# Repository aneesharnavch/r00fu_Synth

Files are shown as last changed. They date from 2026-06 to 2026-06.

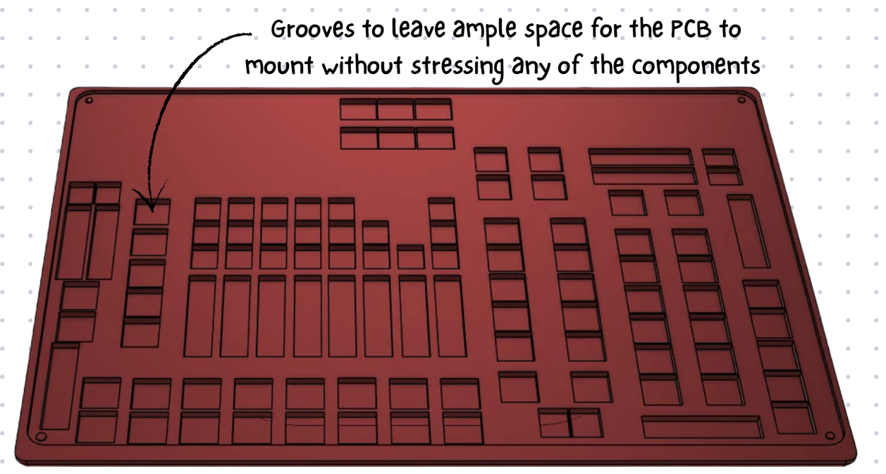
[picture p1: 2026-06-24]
Assets/Assembly_grooves_pic.png

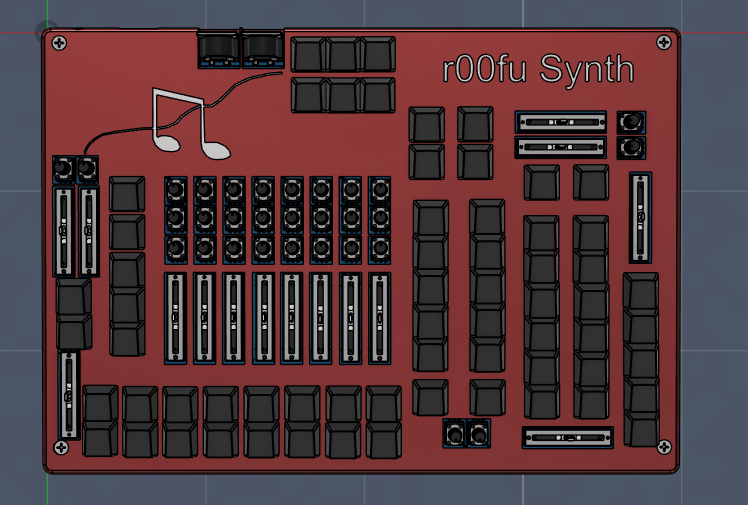
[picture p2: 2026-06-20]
Assets/r00fuSynth_TopDown.png

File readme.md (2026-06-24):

# R00fu Synth
Cover_pic

A digital groove box + synth + MIDI controller crammed into one box. 64 buttons , 25 knobs and 15 sliders to compose any beat you can imagine

# How does it work? 
The primary control is done via an ESP32S3 DevcitC-1 , With its two USB-C ports and it runs on two cores. Core 0 does the digital state checking. It scans all 64 buttons , 25 knobs and 15 sliders once every 1ms reading it through a 74HC4067 Analog MUX chip, It also checks for MIDI in Signal and runs the sequencer. Core 1 only uses the I2S protocol driving audio through the PCM5102A.

It connects to your device by either the USB-C port or DIN MIDI sockets. With everything configured using a modded version of an opensource MIDI configuring python script that runs on a lil python GUI. 

# Why did I make it? 

My friend ( on SoundCloud @r00fu ) is really into music , so being the great friend I am was shocked at how expensive most of the music gear he has is . So me being the dumbass I am proceed to underestimated how complex making a Synthesizer is and try to make one. This is my attempt at going for it. 

# Components Required for the Build

| No. | Quantity | Description | Supplier | Supplier Part | Product Link | Cost | Price (USD) |
|-----|---|---|---|---|---|---|---|
| 1 | 7 | 100nF 0402 Decoupling Capacitor | LCSC | C2888326 | https://www.lcsc.com/product-detail/C2888326.html | 0.00093 | 0.00651 |
| 2 | 6 | 10uF 0402 Decoupling Capacitor | LCSC | C307415 | https://www.lcsc.com/product-detail/C307415.html | 0.1492  | 0.8952 |
| 3 | 4 | 1uF 0603 Charge bank Capacitor | LCSC | C519560 | https://www.lcsc.com/product-detail/C519560.html | 0.0181  | 0.0724 |
| 4 | 1 | 3.5mm Headphone Jack | LCSC | C41347691 | https://www.lcsc.com/product-detail/C41347691.html | 2.273 | 2.273 |
| 5 | 64 | 1N4148W Diode for Switches | LCSC | C917030 | https://www.lcsc.com/product-detail/C917030.html | 0.0061  | 0.3904 |
| 6 | 3 | 220Ω 0603 Resistor | LCSC | C114683 | https://www.lcsc.com/product-detail/C114683.html | 0.00017 | 0.00051 |
| 7 | 1 | 10kΩ 0603 Resistor | LCSC | C95204 | https://www.lcsc.com/product-detail/C95204.html | 0.0241  | 0.0241 |
| 8 | 30 | 10kΩ Knob Potentiometer | LCSC | C209779 | https://www.lcsc.com/product-detail/C209779.html | 0.8401  | 25.203 |
| 9 | 15 | 10kΩ Slide Potentiometer | LCSC | C5357832 | https://www.lcsc.com/product-detail/C5357832.html | 2.82 | 42.3 |
| 10  | 2 | DIN connector for MiDi | LCSC | C2939347 | https://www.lcsc.com/product-detail/C2939347.html | 0.3249  | 0.6498 |
| 11  | 1 | Optocoupler for MiDi In setup | LCSC | C20082 | https://www.lcsc.com/product-detail/C20082.html | 0.5521  | 0.5521 |
| 12  | 1 | Amplifier for Headset/Speaker use | LCSC | C1520792 | https://www.lcsc.com/product-detail/C1520792.html | 2.1817  | 2.1817 |
| 13  | 3 | Analog Multiplexer for device management | LCSC | C1545936 | https://www.lcsc.com/product-detail/C1545936.html | 2.71 | 8.13 |
| 14  | 64 | Mechanical Switches | LCSC | C49234238 | https://www.lcsc.com/product-detail/C49234238.html | 0.1068  | 6.8352 |
| 15  | 1 | ESP32-S3-DevKitC-1 Wifi & Blutooth Dev Board | Aliexpress | S3-DevkitC-1-N32R16V | https://www.aliexpress.com/item/1005003979778978.html | 15.52 | 15.52 |
| 16  | 1 | PCB | JLCPCB | NA | https://cart.jlcpcb.com/quote? | 28.4 | 28.4 |
| | | | | | | Total | 133.43392 |
# PCB and Schematic 
I designed it in EasyEDA Pro. You can find the Gerber files in the repo. The schematic and PCB are as follows : - 
SCH_Schematic_r00fu_Synth
PCB_pic

# Assembly 

Please do note that these assembly instructions are not final and can change. I've yet to build it, and when I do, I'll update this section to be more accurate. In the meanwhile, don't be afraid to change things up or make use of the several exposes GPIO pins/testing pad to make any modifications you would like to make. 

Note : Soldering Instructions are SUGGESTIONS and are typically personal preference , If your used to doing things a certain way , do not change it. I personally tend to do SMD components close to THT components first , followed by the THT components . 

1. Since most of the components on this board are THT anyways , I would recommend you start things off by getting all 24 SMD components soldered on. 
2. You can do that by just soldering one end of the SMD capacitor or resistor down with a decent bit of flux to get the part in place 
3. you can follow that up by soldering the other end cleaning the solder joint before checking for continuity on the passives with a multimeter to just verify its alright 
4. Now that you should be done with the SMD parts, you can begin with placing all of the THT components into their place which should be pretty obvious based on physical appearance 
5. I like to be lazy so I usually tape it down from the top to hold onto the parts when i flip the board over to solder the THT elements 
6. Once you've placed all of the parts down (The tape part is optional, feel free to continue without it) , flip the board around and flux the joints up and solder them nice and snug .
7. Make sure the  buttons are snug and level with the bottom before you let the solder reflow and solidify on the joints. The case will be slightly misaligned if you don't solder things in all the way down .
8. Inspect everything with your eyes , looking at every component individually. Its recommended to use an Multimeter or an LCR meter to just sanity check all of the values and check for continuity on all of your passives (you can also sanity check the sliders and knobs if you just plug the board with power)
9. Use some Isopropanol to clean the Flux and solder residue off the board and connect it to a power source to make sure it doesn't explode.

# Case 
The case is a beautiful rectangular enclosure with cutouts for the Knobs, Sliders and Switches with room left for the Keycaps to be put on after assembly. I added a hackclub logo to the back for some represent, pictures showing it are here below : - 

Case_pic
Internal_case_space
r00fuSynth_base

# Setting up the case

The PCB without keycaps on should just drop onto the bottom plate of the case and you can align the top plates without much difficulty. Once your done with that , just slot in 4 M4 screws through the screw holes and shown in this picture below and you should be done : - 
r00fuSynth_Assembly_pic
Screw_mount_pic
# Hardware at a Glance 

| Subsystem | What it is |
| --- | --- |
| MCU | ESP32S3-S3-DevkitC1 Dev Board |
| Audio | PCM5102A I2S DAC, 44.1kHz/16-bit stereo audio system |
| Buttons | 8x8 matrix with key diodes , scanned every 1ms |
| Knobs | 25 pots read via 2 MUXes |
| Sliders | 15 Faders read via 3rd MUX |
| MUX | 3 x 74HC4067 (16CH MUX) |
| MIDI | 5 pin DIN in/out boards |
| FX | delay , reverb , chorus , bitcrusher |
# Setting up the Firmware 

The firmware builds on PlatformIO (not the Arduino IDE or the ESP32 IDF) as the code is dependent very much so on several other opensource libraries. 

1. Install PlatformIO if you haven't done so yet , run the following commands in terminal
```cmd
pip install platformio 
pio --version 
```
2. PLUG INTO THE CORRECT USB-C PORT. The DevKitC-1  has two USB-C ports. USE THE USB PORT , NOT THE UART ONE. 
3.  Flashing the firmware for the first time needs you to enter board in boot mode so just 
	**hold `BOOT` → tap `RESET` → release `BOOT`**
4. Flash some sort of test sketch to sanity check the board before flashing the firmware using the PlatformIO cli, Just run the following snippet of CMD commands 
```cmd
cd firmware/r00fu_synth
pio run -t uploadfs # settings and partition 
pio run -t upload # the actual firmware
```
once you get the following message on the terminal , You should be done ! 

```cmd
Verifying written data...
Hash of data verified.

Hard resetting via RTS pin...
```
5. Watch it boot:
```cmd
pio device moonitor -b 115200
```
Its done properly if you see : 
```cmd
HELLO r00fu_synth 0.20
LOG r00fu_synth boot complete 
```
pressing any key or move and knob or slider and the serial monitor should spit out the exact id and state of whatever key/knob/slider you've messed with. So you should be done with uploading code onto the board , now time to configure it for your application. 
# Pin map 

This is the wiring the firmware expects. It's all in `include/config.h` , Its the only source of global definitions in the code.

| What | name in code | GPIO pin | Notes |
|---|---|---|---|
| Switch Matrix Rows | ROW_PINS | 4,5,6,7,15,16,17,18 | Low when not in Use |
| Switch Matrix Columns | COL_PINS | 8,9,10,11,12,13,14,21 | Reading with internal pull up |
| MUX select pins | MUX_SEL_PINS | 35,36,37,38 | Shared by all MUX |
| MUX A out | MUX_A_OUT | 1 | MUX A read pin |
| MUX B out | MUX_B_OUT | 2 | MUX B read pin |
| MUX C out | MUX_C_OUT | 3 | MUX C read pin |
| I2S Bit Clock | I2S_BCK_PIN  | 40 | PCM5102A BCK |
| I2S Word Clock | I2S_LRCK_PIN | 41 | PCM5102A LRCK |
| I2S Data | I2S_DOUT_PIN | 42 | PCM5102A DIN |
| MIDI OUT | MIDI_TX_PIN  | 43 | DIN out with current limit |
| MIDI IN | MIDI_RX_PIN  | 44 | DIN in through optocoupler |
# Setting up the the Hardware config ( the software that maps the buttons)

This is the part of the firmware that actually makes the Synth work. run the ``gui/r00fu_config.py`` file to communicate with the synth across USB serial. Pressing a physical button should light up a square on the python GUI and you can configure it  a bunch of different applications. To run it , you only really need python and pyserial installed. If you don't have that done already, just run the following command in your terminal. 

```cmd
pip install pyserial
```

1. run the file now and you should see a dropdown to select the boards COM port 
2. Select the board's COM port and hit connect, the status bar should say some form of connected 
3. once you click a button IRL , you should see it flash in the python script, now on the python script , you can pick one of the functions from the panel : 

| Function  | What it does |
| --- | --- |
| Note | plays a MIDI note (on the synth and out of USB/DIN) |
| CC | command to change MIDI controller (127 on press, 0 on release) |
| Program | sends a program change |
| Transport | Play/ Stop / Record / Continue etc.. |
| Mode | switches the whole box to Drum/StepSeq/Keyboard etc.. |
| None | does nothing |
4. Push to the Device , Sends the whole command map over serial. This data is Saved 
5.  Save/Load dumps the map to a config .json file 
# First boot and Setup 
- Plug into the USB port and plug in Headphones or an Amp into the PCM5102A's Headphone jack
- It should boot straight into Drum mode (LED should go yellow). assuming you've set the config with drum notes on the hardware config. 
- Turn a knob , the synth should reach. If knobs feel jittery/laggy then please increase the `ANALOG_SMOOTHING` parameter in the code
- Have a blast , it appears to be working as intended 

If you do run into issues ? Most of the time its :- 
- Wrong USB port
- button not mapped to note yet 
- SCK not tied to ground properly
# Some examples of actually using it 

This is the fun part. The box is **5 instruments**, and you flip between them with a button you mapped to **Mode** (or send it from the GUI). The LED colour tells you where you are.

### Mode 0 Drum Machine :
8 drum tracks, the grid is your pads. Each pad is mapped (in the GUI) to a note that triggers a drum voice. Tap pads to play in real time.

### Mode 1 Step Sequencer :

The 64 buttons are physically wired to resemble a keyboard with 64 Switches, Some of the things you can use the boat for are :

- mute/unmute tracks
- parameter locks
- swing 
- pattern chaining

### Mode 2 Keyboard : 

The grid becomes notes. Set you need to setup a  scale In the python script so every key you hit is in-key. Use **chord mode** to slam triads with the buttons and move notes around with the slider

### Mode 3  DAW Controller :

It's a USB-MIDI control surface. So you can just plug the USB port into your computer, open your DAW, and configure the following items :- 
- buttons (Can be mapped to litterally anything a macro can be mapped to )
- 25 knobs (map them to plugin params, sends, whatever)
- 15 sliders  (for faders or volume for individual subtracks)  
    Everything leaves over USB-MIDI for the host to learn. This is the "I want the full DAW but I hate the mouse" mode.

# Code Tweaks / Example implementation

You can tune the switch matrix input stuff by changing
include/config.h:
```cpp
static const int ROW_PINS[MATRIX_ROWS] = { 8, 9, 10, 11, 12, 13, 14, 21 }; // COLS
static const int COL_PINS[MATRIX_COLS] = { 4, 5, 6, 7, 15, 16, 17, 18 };   //ROWS
```

If your Knobs too jittery / too sluggish: change the smoothing. General Rule of Thumb Higher = smoother but laggier.
include/config.h:
```cpp
#define ANALOG_SMOOTHING 0.10f   
```

Buttons feel weird / mis-inputs: tune the debounce (how many stable 1 ms samples before it commits).
include/config.h:
```cpp
#define MATRIX_DEBOUNCE_COUNT 6  // lower = snappier but bouncier and vice versa
```

If you want more voices or want to prioritize vocals change : 
include/config.h:
```cpp
#define NUM_VOICES 8  
```

# Files 
```cmd
C:.
│   BOM_r00fu_synth.csv
│   readme.md
│   Zine_r00fu_Synth.pdf
│
├───Assets
│       PCB_3D_Render_No_assembly_pic.png
│       PCB_pic .png
│       r00fuSynth_Assembly.png
│       r00fuSynth_Assembly_pic.png
│       r00fuSynth_base.png
│       r00fuSynth_TopDown.png
│       SCH_Schematic_r00fu_Synth.png
│       Zine_r00fu_Synth.png
│
├───CAD_Files
│       r00fusynth.f3z
│       r00fusynth.step
│
├───Firmware
│   ├───gui
│   │   │   r00fu_config.py
│   │   │   README.md
│   │   │
│   │   └───__pycache__
│   │           r00fu_config.cpython-314.pyc
│   │
│   ├───prototype_single_file
│   │       r00fu_synth_prototype.ino
│   │
│   └───r00fu_synth
│       │   platformio.ini
│       │   SETUP.md
│       │
│       ├───data
│       ├───include
│       │       config.h
│       │       events.h
│       │       midi_map.h
│       │
│       └───src
│           │   main.cpp
│           │
│           ├───audio
│           │       adsr.cpp
│           │       adsr.h
│           │       effects.cpp
│           │       effects.h
│           │       filter.cpp
│           │       filter.h
│           │       oscillator.cpp
│           │       oscillator.h
│           │       synth.cpp
│           │       synth.h
│           │       voice.cpp
│           │       voice.h
│           │
│           ├───drivers
│           │       button_matrix.cpp
│           │       button_matrix.h
│           │       config_protocol.cpp
│           │       config_protocol.h
│           │       midi_din.cpp
│           │       midi_din.h
│           │       mux.cpp
│           │       mux.h
│           │       pcm5102.cpp
│           │       pcm5102.h
│           │       usb_midi.cpp
│           │       usb_midi.h
│           │
│           ├───sequencer
│           │       sequencer.cpp
│           │       sequencer.h
│           │
│           ├───storage
│           │       midi_map.cpp
│           │       presets.cpp
│           │       presets.h
│           │       settings.cpp
│           │       settings.h
│           │
│           ├───system
│           │       events.cpp
│           │       tasks.cpp
│           │       tasks.h
│           │
│           └───ui
│                   modes.cpp
│                   modes.h
│
└───PCB_Files
        Gerber_r00fu_Synth.zip
        PickAndPlace_r00fu_Synth .xlsx
        Source_r00fu_Synth .epro
```
# Zine 
Zine_r00fu_Synth

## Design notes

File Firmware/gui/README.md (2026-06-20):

# r00fu_synth — Button Configurator

A desktop tool to **detect** every physical button on the groovebox and
**map** each one to a function (MIDI note / CC / Program / Transport / Mode).
Built for a music producer: the same map drives the standalone groovebox *and*
turns it into a USB-MIDI control surface in Ableton / FL / Reaper / Bitwig.

## Setup
```
pip install pyserial
python r00fu_config.py
```
(Tkinter ships with standard Python on Windows.)

## Workflow
1. Flash `../firmware/r00fu_synth/r00fu_synth.ino` to the ESP32-S3
   (Arduino IDE → ESP32S3 Dev Module → **USB CDC On Boot: Enabled**).
2. Open the GUI, pick the COM port, **Connect**.
3. **Press a physical button** → the matching cell flashes green. That's how you
   find/verify keys.
4. **Learn mode**: tick it, click a cell, press the key you want — selection
   jumps to that key so you can assign it without hunting.
5. Pick a Function in the right panel, set channel/value/label, **Apply**.
6. **Save…** to JSON, and **Push to Device** to send the live map over serial.

## Serial protocol
115200 baud, newline ASCII. Full spec is in the firmware header.
| Dir | Message | Meaning |
|-----|---|---|
| ← | `HELLO r00fu_synth 0.1.0` | device announce |
| ← | `BTN <idx> <row> <col> <0\|1>` | button edge |
| → | `MAP <idx> <type> <ch> <val> <label>` | store mapping |
| → | `IDENTIFY` / `DUMP` | query device |
| ← | `ACK MAP <idx>` | mapping stored |

`idx = row*8 + col` (0..63). `type`: 0 none, 1 note, 2 cc, 3 program, 4 transport, 5 mode.

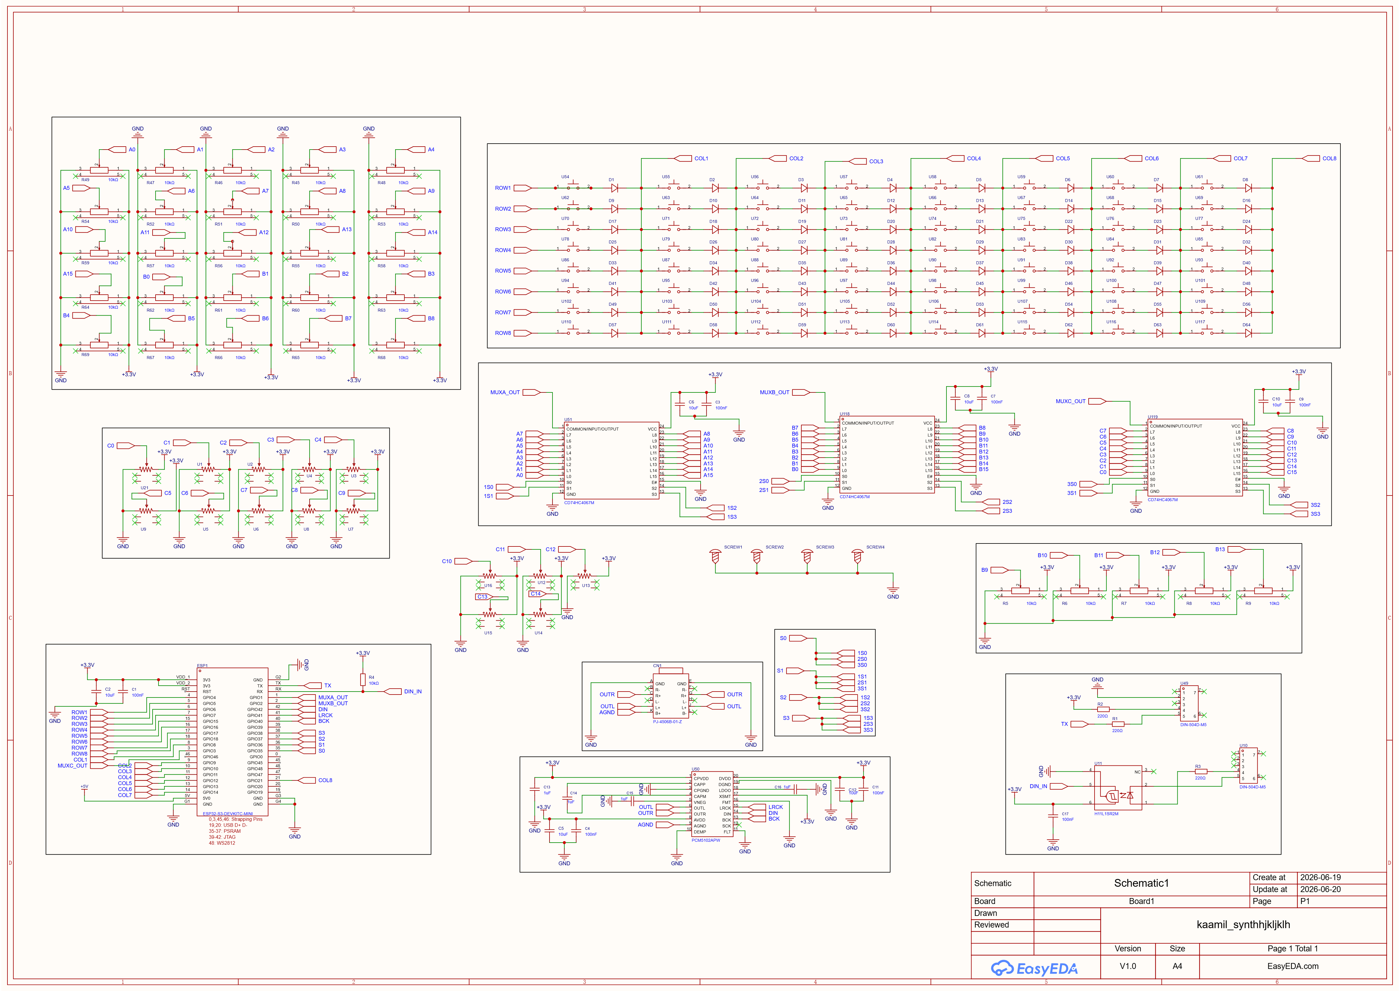
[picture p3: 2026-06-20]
Assets/SCH_Schematic_r00fu_Synth.png

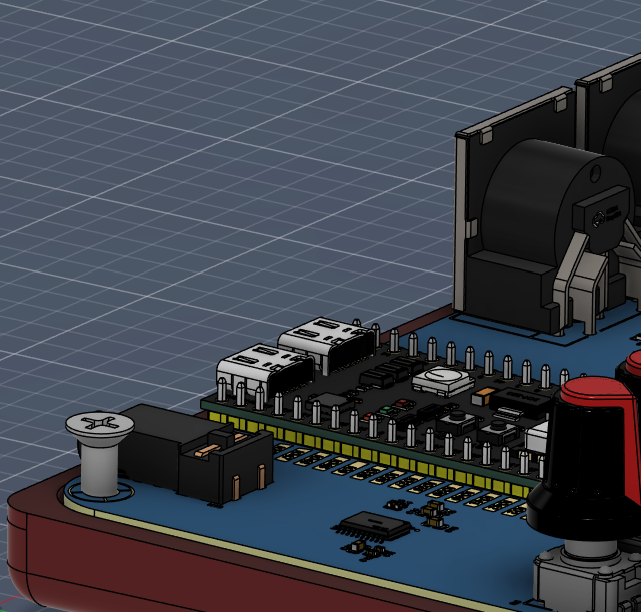
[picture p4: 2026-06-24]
Assets/Screw_mount_pic.png

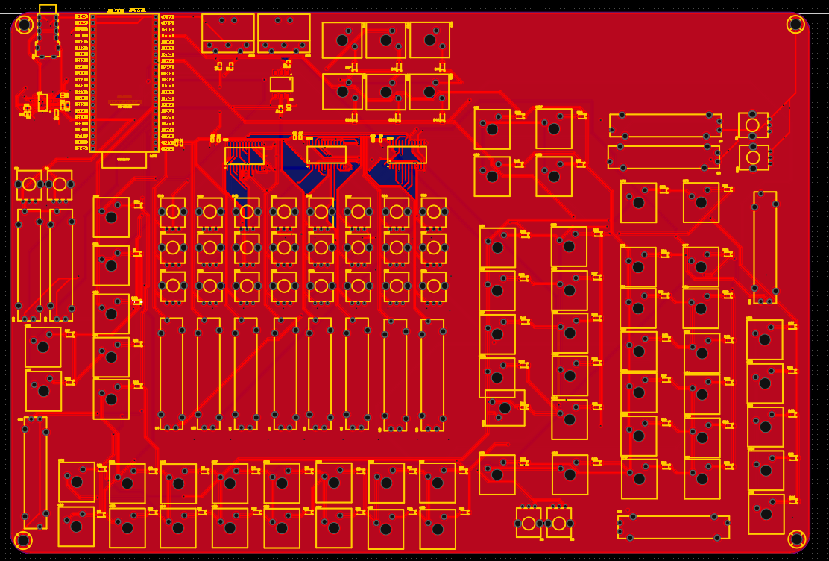
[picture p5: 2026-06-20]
Assets/PCB_pic .png

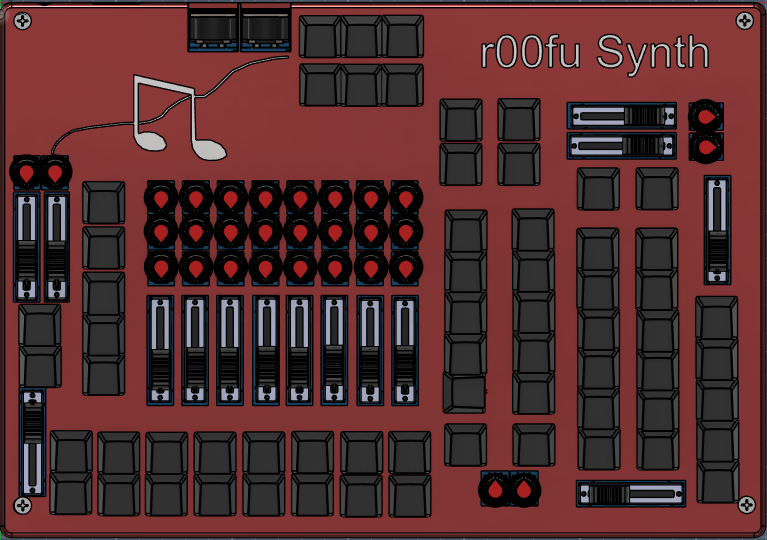
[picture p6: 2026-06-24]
Assets/Cover_pic.png

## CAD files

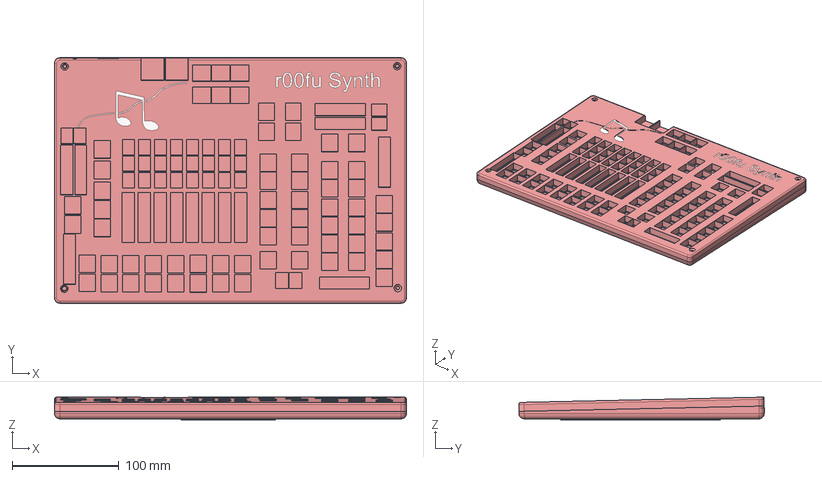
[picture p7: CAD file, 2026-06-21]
CAD_Files/r00fusynth.step
330.0 x 230.2 x 21.4 mm

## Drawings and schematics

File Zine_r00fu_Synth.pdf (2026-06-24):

## a really cool custom synth pad

# r00fu Synth

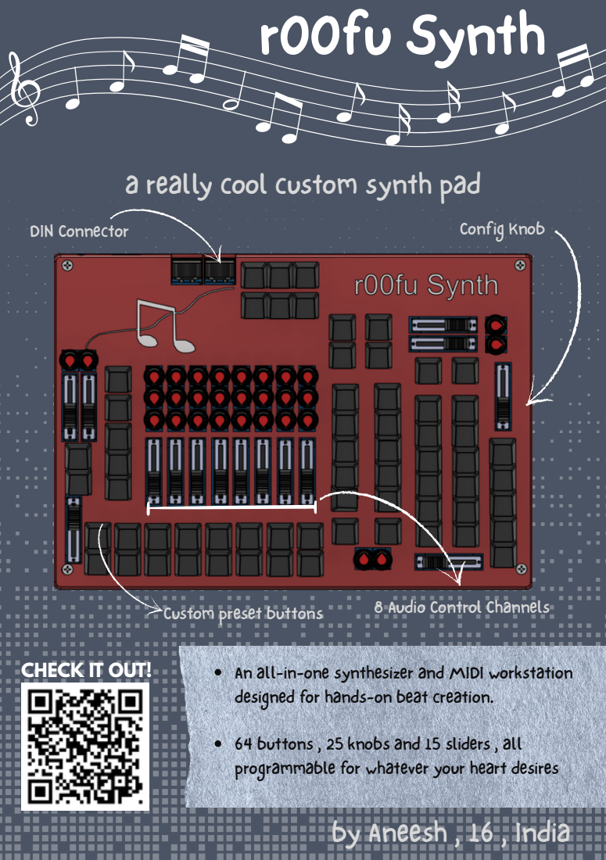
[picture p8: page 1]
DIN Connector; Config Knob

8 Audio Control Channels

Custom preset buttons
An all-in-one synthesizer and MIDI workstation
designed for hands-on beat creation.
64 buttons , 25 knobs and 15 sliders , all
programmable for whatever your heart desires
by Aneesh , 16 , India

CHECK IT OUT!

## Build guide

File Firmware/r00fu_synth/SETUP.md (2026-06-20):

# r00fu_synth — Setup Guide (zero to sound)

This is the single guide a person follows to take a bare **ESP32-S3-DevKitC-1** and
the r00fu_synth hardware (8x8 button matrix, 3x analog muxes for 25 knobs + 15
sliders, a PCM5102A I2S DAC, and 5-pin DIN MIDI) and turn it into a working
**groovebox + USB-MIDI controller + standalone polyphonic synth**.

Follow the sections **in order**. Commands are copy-paste ready for Windows.

---

## 1. What this is + the libraries it leans on

r00fu_synth is firmware for a portable music workstation built on the ESP32-S3
(dual core, 240 MHz). It is five instruments in one box, selectable as **modes**:

| Mode | id | What the 8x8 grid does |
|---|----|---|
| Drum | 0 | drum trigger pads (per-button map) |
| StepSeq | 1 | 64-step sequencer: rows select track/page/pattern, then edit steps |
| Keyboard | 2 | notes (per-button map) |
| DAW | 3 | clip-launch / control surface — buttons, knobs, faders all leave over USB-MIDI |
| Performance | 4 | momentary live FX (filter sweep on held pads) |

The whole point of the project is to **lean on mature open-source libraries**
instead of reinventing them. The firmware pulls these in via PlatformIO
(`platformio.ini` → `lib_deps`):

| Library | Why it is here |
|---|---|
| **FortySevenEffects MIDI Library** | Parses/serializes 5-pin **DIN MIDI** on UART1. |
| **Adafruit TinyUSB** | The native USB stack — exposes a **composite USB-MIDI + USB-CDC** device so the same cable is both a DAW MIDI port and the GUI's serial console. |
| **ResponsiveAnalogRead** | Smooths the 25 knobs + 15 sliders read through the muxes (kills ADC jitter). |
| **ArduinoJson** | Reads/writes presets and settings as JSON on LittleFS. |
| **Adafruit NeoPixel** | Drives the on-board WS2812 status LED (per-mode colour + activity blink). |

The synth/effects DSP is adapted from **ML_SynthTools / AcidBox** patterns but is
self-contained, so it compiles without that library. (`platformio.ini` has a
commented `marcel-licence/ML_SynthTools` line if you ever want to swap engines.)

---

## 2. Prerequisites (Windows)

You need Python (for PlatformIO CLI and the GUI), then PlatformIO itself.

**PlatformIO CLI** — the simplest path is via pip:

```powershell
python -m pip install --upgrade platformio
pio --version
```

If `pio` is not found afterward, add Python's `Scripts` folder to your PATH, or
use the full path `%USERPROFILE%\.platformio\penv\Scripts\pio.exe`.

**PlatformIO IDE (VS Code extension)** — recommended for editing/monitoring:

1. Install **VS Code**.
2. Extensions panel (`Ctrl+Shift+X`) → search **PlatformIO IDE** → Install.
3. Reload. A PlatformIO toolbar appears at the bottom. Open this folder
   (`firmware/r00fu_synth`) and it auto-detects the project.

The CH343/native-USB drivers are built into Windows 11. (Only the *UART* port,
section 3, may pop a "CP210x / CH340" driver request — you generally won't use it.)

---

## 3. The TWO USB-C ports — plug into "USB", not "UART"

The DevKitC-1 has **two USB-C connectors side by side**:

- **UART** — goes through a USB-to-serial bridge chip. This is the classic
  "always works for flashing" port, but it is **not** a real USB device — it
  cannot be a USB-MIDI port, and it shares the bridge with our DIN MIDI UART pins.
- **USB** — the ESP32-S3's **native USB** peripheral. **Use this one.**

**Plug into the port silkscreened `USB`.** This firmware is built with
`-DARDUINO_USB_MODE=0` (TinyUSB) and `-DARDUINO_USB_CDC_ON_BOOT=1`, so the native
port enumerates as a **composite device**: a USB-MIDI port for your DAW *and* a
USB-CDC serial port for the GUI/console, simultaneously. The UART port can't do
that, and the DIN MIDI lines (`GPIO43/44`) are physically the bridge's
`U0TX/U0RX` — keeping the bridge idle avoids contention. See `config.h` for the
exact note.

**First-time flashing / "download mode".** On a fresh board the native USB device
may not be enumerated yet, so the uploader can't auto-reset it into the
bootloader. If an upload hangs at *"Connecting…"*, put the board in download mode
by hand:

1. Press and **hold `BOOT`**.
2. **Tap `RESET`** (a.k.a. `EN`) once.
3. **Release `BOOT`**.

The chip is now in ROM download mode. Run the upload again. After the first
successful flash, subsequent uploads usually auto-reset and you won't need this.

---

## 4. First-time flash

From this directory (`firmware/r00fu_synth`). Do these **in this order** — the
filesystem image first, then the firmware.

**A) Upload the LittleFS data partition (presets/settings):**

```powershell
pio run -t uploadfs
```

This builds the `data/` folder into a LittleFS image and writes it to the flash
partition reserved in `default_16MB.csv`. The `data/` folder is currently empty,
which is fine — the firmware **formats LittleFS on first boot** and writes a
factory mapping + default settings itself. Running `uploadfs` once guarantees the
partition exists and is clean. (If your module is the 8 MB "N8" variant, switch
`board_build.partitions = default_8MB.csv` in `platformio.ini` first.)

**B) Upload the firmware:**

```powershell
pio run -t upload
```

`pio run` builds first (downloading the `lib_deps` on the first run — give it a
minute), then flashes.

**Selecting the COM port.** PlatformIO auto-detects in most cases. To be explicit:

```powershell
pio device list
```

Find the port for the **native USB** device (e.g. `COM7`), then pin it in
`platformio.ini` under `[env:esp32-s3-devkitc-1]`:

```ini
upload_port  = COM7
monitor_port = COM7
```

**What success looks like.** Open the serial monitor:

```powershell
pio device monitor -b 115200
```

On boot the device prints (this is the GUI protocol, section 7):

```
HELLO r00fu_synth 0.2.0
LOG r00fu_synth boot complete
```

Pressing a physical button prints `BTN <index> <row> <col> 1` on press and
`... 0` on release. The on-board RGB LED lights in the current mode's colour
(amber = Drum at default). If a PCM5102A and headphones/amp are wired to
`BCK=40 / LRCK=41 / DOUT=42`, playing a mapped note makes sound.

---

## 5. PSRAM-off decision (and how to turn it back on)

**Why PSRAM is OFF by default.** The three analog-mux select lines `S0/S1/S2`
reuse **GPIO 35/36/37**, which on this module are the **octal-PSRAM bus**. You
can't have both. We ship with **PSRAM disabled** (`-DBOARD_HAS_PSRAM=0`) so the
wiring you already have works unchanged. The synth (8 voices + effects) fits
comfortably in internal SRAM, so nothing is lost for normal use.

**If you ever want PSRAM** (e.g. for samples/looper stretch goals), you must move
those three select lines off the PSRAM pins — a **3-jumper rewire**:

| Mux select | Move FROM | Move TO |
|---|---|---|
| S0 | GPIO 35 | **GPIO 39** |
| S1 | GPIO 36 | **GPIO 47** |
| S2 | GPIO 37 | **GPIO 48** |

(`S3` on GPIO 38 stays put. Note GPIO 48 is the status LED's default pin — relocate
the LED too, or accept the conflict, when you go down this road.)

Then update `MUX_SEL_PINS[]` in `include/config.h` to `{39, 47, 48, 38}`, and
build/flash the PSRAM environment, which re-enables octal PSRAM:

```powershell
pio run -e esp32-s3-devkitc-1-psram -t upload
```

That env (`platformio.ini`) flips `-DBOARD_HAS_PSRAM=1` and sets
`board_build.arduino.memory_type = qio_opi`.

---

## 6. How to USE it

### Configure buttons with the PC GUI

The GUI (`gui/r00fu_config.py`) lights up an on-screen 8x8 grid live as you press
keys, and lets you assign a function to each button, then push it to the device.

```powershell
python -m pip install pyserial
python ../../gui/r00fu_config.py
```

1. **Port** dropdown → pick the device's COM port → **Connect**. The status bar
   shows `Device: HELLO r00fu_synth 0.2.0`.
2. **Press a physical button** — the matching on-screen cell flashes green. This
   is how you find/verify every key. (Tick *Learn mode* to auto-select the cell
   you press.)
3. **Click a cell**, choose a **Function** (Note / CC / Program / Transport /
   Mode / None), set channel + value + label, **Apply**.
4. **Push to Device** sends the whole map over serial; the firmware acts on it
   standalone *and* persists it to LittleFS.
5. **Save…/Load…** stores the map as JSON for later.

### Use as a USB-MIDI controller in a DAW

Plug the **USB** port into your computer. The composite device exposes a
**USB-MIDI port** named for the board. In Ableton/FL/Reaper/Bitwig, enable it as a
MIDI input. Now:

- In **DAW mode**, the 64 buttons, 25 knobs, and 15 sliders all emit MIDI that
  the host can learn (knobs → CC 16.., faders → CC 0.., buttons → your mapped
  notes/CC). Knobs/faders are always sent out USB in this mode.
- In other modes, any button you mapped to a Note/CC/Program also mirrors out
  USB-MIDI, so the box doubles as a controller while it plays its own synth.

### DIN MIDI in/out

Wire 5-pin DIN through the standard opto-isolated input (6N138 / H11L1) on
`GPIO44` (**MIDI IN**) and a current-limited output on `GPIO43` (**MIDI OUT**),
both at 31250 baud on UART1. The box:

- plays incoming DIN notes on its synth and can **slave to incoming MIDI clock**,
- sequences external gear and can act as **clock master** out both ports,
- transparently bridges **USB ↔ DIN** without echo loops (a message that arrived
  on one port is never sent back out that same port).

---

## 7. Serial protocol + the 5 modes

The GUI link rides on **USB-CDC `Serial` at 115200 baud**, newline-terminated
ASCII. It is a separate USB interface from USB-MIDI — they never mix.
(`src/drivers/config_protocol.cpp`.)

**Device → PC**

| Line | Meaning |
|---|---|
| `HELLO r00fu_synth <fwver>` | sent on boot and in reply to `IDENTIFY` |
| `BTN <index> <row> <col> <0\|1>` | button edge (1 = press, 0 = release) |
| `ACK MAP <index>` | a mapping was stored |
| `MAP <index> <type> <ch> <val> <label>` | one row emitted by `DUMP` |
| `LOG <text>` | human-readable debug |

**PC → Device**

| Line | Meaning |
|---|---|
| `IDENTIFY` | ask the device to announce itself |
| `MAP <index> <type> <ch> <val> <label...>` | store a mapping (rest of line = label; `-` = none) |
| `DUMP` | echo every stored mapping back as `MAP` lines |

`index = row * 8 + col` (0..63). `type` is the **MapType** (`include/midi_map.h`),
which must stay in lock-step with the GUI's `TYPES` dict:

| type | MapType | `value` means |
|---|---|---|
| 0 | NONE | (no action) |
| 1 | NOTE | MIDI note 0..127 |
| 2 | CC | CC number 0..127 (momentary: 127 on press, 0 on release) |
| 3 | PROGRAM | program 0..127 |
| 4 | TRANSPORT | 0 Play · 1 Stop · 2 Record · 3 Continue · 4 TapTempo |
| 5 | MODE | 0 Drum · 1 StepSeq · 2 Keyboard · 3 DAW · 4 Performance |

The five **modes** are the table in section 1; map a button to MapType **5** to
switch between them on the device.

---

## 8. Troubleshooting

**No serial port shows up.**
- Make sure you're on the **USB** (native) port, not **UART**.
- Re-run `pio device list`. If still nothing, the device may not have enumerated —
  enter download mode (hold `BOOT`, tap `RESET`, release `BOOT`) and re-flash;
  the firmware brings USB-CDC up in `setup()`.
- Close any other program (the GUI, another monitor) holding the port — only one
  can own it at a time.

**Board won't enter / stay in download mode.**
- Sequence matters: **hold `BOOT` → tap `RESET`/`EN` → release `BOOT`**, *then*
  start the upload.
- A flaky USB-C cable is the #1 cause — many cables are charge-only with no data
  lines. Swap it. Try a different USB port / avoid hubs.

**No audio.**
- The PCM5102A needs **`SCK` tied to GND** — this firmware runs the DAC in
  PLL/software mode with no MCLK pin (`pcm5102.cpp`). A floating SCK = silence.
- Check `BCK=GPIO40`, `LRCK=GPIO41`, `DOUT=GPIO42`, plus `VIN`/`GND` and the
  PCM5102A's `FLT/DEMP/XSMT/FMT` config pins per its board.
- Confirm a button is actually **mapped to a Note** and you're in a synth mode
  (Drum/Keyboard) — DAW mode sends MIDI out rather than driving the local synth.

**MIDI not received (DIN).**
- DIN IN must go through an **opto-isolator** (6N138/H11L1) into `GPIO44`; a bare
  DIN socket won't work and can be unsafe.
- Check baud is 31250 and the IN/OUT sockets aren't swapped.
- USB-MIDI not seen by the DAW? You're probably on the **UART** port — move to
  **USB**.

**Buttons ghosting / phantom presses / inverted.**
- The matrix needs a **per-key diode** for N-key rollover. If keys read inverted
  or trigger neighbours, your diodes are reversed. The fix is a one-liner: swap
  the ROW/COL roles (drive columns, read rows) — flip `ROW_PINS`/`COL_PINS` in
  `include/config.h`. The scan drives one row LOW and reads columns with pull-ups.

---

## 9. Build order / phase status

The firmware follows the spec's phase plan (`instructions.txt`). Boot order and
task placement are real and final (`src/main.cpp`, `src/system/tasks.cpp`): all
scanners, MIDI, sequencer, and the UI dispatcher are pinned to **CORE_IO (0)**;
the audio render loop is the sole task on **CORE_AUDIO (1)** at the highest
priority, and the only place that touches DSP. Hardware scanners only
`event_post()`; the dispatcher routes; musical actions reach the synth through an
RT-safe core0→core1 command queue (`src/audio/synth.h`).

| Phase | Area | Status |
|---|---|---|
| 1 | Button matrix (8x8, 1 ms scan, debounce) | **functional** |
| 2 | Analog muxes (knobs/sliders, smoothing) | **functional** |
| 3 | USB-MIDI (TinyUSB composite) | **functional** |
| 4 | DIN MIDI (UART1, 47Effects lib) | **functional** |
| 5 | Sequencer (8 track / 64 step, clock, swing) | **functional** |
| 6 | Synth engine (8-voice poly) | **functional, self-contained DSP** |
| 7 | Effects (delay/reverb/chorus/bitcrusher) | **functional, tunable** |
| 8 | Presets/settings (LittleFS + ArduinoJson) | **functional** |
| 9 | Performance FX (momentary filter sweep) | **basic/scaffolded** |
| 10 | Microphone (reactive FX, looper, vocoder) | **not implemented** |

GUI config protocol (HELLO/BTN/MAP/IDENTIFY/DUMP) is **functional** and matches
`gui/r00fu_config.py` exactly. Stretch goals (SD card, sampling, wavetables,
euclidean sequencer, USB firmware update) are **not started**.

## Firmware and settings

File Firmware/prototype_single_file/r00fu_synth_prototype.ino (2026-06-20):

/*
 * r00fu_synth — STUB FIRMWARE (Phase 1 + protocol)
 * ------------------------------------------------
 * Goal of this sketch: get the 8x8 button matrix scanning and emit a clean
 * USB-serial event stream that the PC GUI (gui/r00fu_config.py) consumes,
 * and accept button->function mappings back from the GUI.
 *
 * This is intentionally minimal. It is the foundation that Phase 2+ (mux,
 * MIDI, sequencer, synth) bolts onto. It does NOT make sound yet.
 *
 * Board: ESP32-S3 Dev Module
 *   - USB CDC On Boot: ENABLED   (so Serial = native USB, debug console)
 *   - PSRAM: see note below about GPIO 35/36/37
 *
 * SERIAL PROTOCOL (115200 baud, newline-terminated ASCII)
 *   Device -> PC:
 *     HELLO r00fu_synth <fwver>      sent on boot and on IDENTIFY
 *     BTN <index> <row> <col> <0|1>  button edge (1=press, 0=release)
 *     ACK MAP <index>                mapping stored
 *     LOG <text>                     human-readable debug
 *   PC -> Device:
 *     IDENTIFY                       ask device to announce itself
 *     MAP <index> <type> <ch> <val> <label...>   store a mapping
 *     DUMP                           echo all stored mappings as MAP lines
 *
 * index = row * 8 + col   (0..63)
 */

#include <Arduino.h>

#define FW_VERSION "0.1.0"

// ---- Pinout (from pinouts.txt) -------------------------------------------
static const uint8_t ROW_PINS[8] = { 4, 5, 6, 7, 15, 16, 17, 18 };
static const uint8_t COL_PINS[8] = { 8, 9, 10, 11, 12, 13, 14, 21 };

// Matrix scan: drive one ROW LOW at a time, read COLUMNS with pull-ups.
// A pressed key pulls its column LOW. Per-key diodes give N-key rollover.
// If your diodes are oriented the other way and keys read inverted/ghost,
// flip ROW/COL roles here (drive cols, read rows) — that's the only change.

static const uint32_t SCAN_INTERVAL_MS = 1;   // 1ms scan (spec)
static const uint8_t  DEBOUNCE_COUNT   = 6;   // ~6ms stable before commit

// ---- Mapping store --------------------------------------------------------
// Mirrors the GUI's JSON. Kept tiny; persisted to NVS/LittleFS in a later phase.
enum MapType : uint8_t { MAP_NONE=0, MAP_NOTE=1, MAP_CC=2, MAP_PROGRAM=3,
                         MAP_TRANSPORT=4, MAP_MODE=5 };
struct ButtonMap {
  uint8_t type;     // MapType
  uint8_t channel;  // 1..16 (MIDI) or unused
  uint8_t value;    // note#/cc#/program#/transport id/mode id
  char    label[16];
};
static ButtonMap gMap[64];

// ---- Debounce state -------------------------------------------------------
static uint8_t  stableState[64];   // last committed state
static uint8_t  candCount[64];     // consecutive reads of the candidate
static uint8_t  candState[64];     // candidate state being counted

static uint32_t lastScan = 0;

void announce() {
  Serial.printf("HELLO r00fu_synth %s\n", FW_VERSION);
}

void emitButton(uint8_t index, uint8_t row, uint8_t col, uint8_t pressed) {
  Serial.printf("BTN %u %u %u %u\n", index, row, col, pressed);
}

void scanMatrix() {
  for (uint8_t r = 0; r < 8; r++) {
    digitalWrite(ROW_PINS[r], LOW);          // activate this row
    delayMicroseconds(3);                    // let lines settle
    for (uint8_t c = 0; c < 8; c++) {
      uint8_t idx = r * 8 + c;
      uint8_t pressed = (digitalRead(COL_PINS[c]) == LOW) ? 1 : 0;

      if (pressed == stableState[idx]) {
        candCount[idx] = 0;                  // no change, reset candidate
      } else if (pressed == candState[idx]) {
        if (++candCount[idx] >= DEBOUNCE_COUNT) {
          stableState[idx] = pressed;        // commit
          candCount[idx] = 0;
          emitButton(idx, r, c, pressed);
        }
      } else {
        candState[idx] = pressed;            // new candidate
        candCount[idx] = 1;
      }
    }
    digitalWrite(ROW_PINS[r], HIGH);         // deactivate row
  }
}

void handleLine(char *line) {
  // Tokenize in-place
  char *cmd = strtok(line, " ");
  if (!cmd) return;

  if (!strcmp(cmd, "IDENTIFY")) {
    announce();
  } else if (!strcmp(cmd, "MAP")) {
    char *sIdx = strtok(NULL, " ");
    char *sTyp = strtok(NULL, " ");
    char *sCh  = strtok(NULL, " ");
    char *sVal = strtok(NULL, " ");
    char *sLbl = strtok(NULL, "\n");          // rest of line = label
    if (!sIdx || !sTyp || !sCh || !sVal) return;
    int idx = atoi(sIdx);
    if (idx < 0 || idx > 63) return;
    gMap[idx].type    = (uint8_t)atoi(sTyp);
    gMap[idx].channel = (uint8_t)atoi(sCh);
    gMap[idx].value   = (uint8_t)atoi(sVal);
    if (sLbl) { strncpy(gMap[idx].label, sLbl, 15); gMap[idx].label[15] = 0; }
    else      { gMap[idx].label[0] = 0; }
    Serial.printf("ACK MAP %d\n", idx);
  } else if (!strcmp(cmd, "DUMP")) {
    for (int i = 0; i < 64; i++) {
      Serial.printf("MAP %d %u %u %u %s\n", i, gMap[i].type,
                    gMap[i].channel, gMap[i].value,
                    gMap[i].label[0] ? gMap[i].label : "-");
    }
  }
}

void pollSerial() {
  static char buf[96];
  static uint8_t len = 0;
  while (Serial.available()) {
    char ch = (char)Serial.read();
    if (ch == '\n' || ch == '\r') {
      if (len) { buf[len] = 0; handleLine(buf); len = 0; }
    } else if (len < sizeof(buf) - 1) {
      buf[len++] = ch;
    }
  }
}

void setup() {
  Serial.begin(115200);

  for (uint8_t r = 0; r < 8; r++) {
    pinMode(ROW_PINS[r], OUTPUT);
    digitalWrite(ROW_PINS[r], HIGH);         // idle high (inactive)
  }
  for (uint8_t c = 0; c < 8; c++) {
    pinMode(COL_PINS[c], INPUT_PULLUP);
  }

  memset(stableState, 0, sizeof(stableState));
  memset(candCount, 0, sizeof(candCount));
  memset(candState, 0, sizeof(candState));
  memset(gMap, 0, sizeof(gMap));

  delay(300);                                // let USB-CDC enumerate
  announce();
}

void loop() {
  uint32_t now = millis();
  if (now - lastScan >= SCAN_INTERVAL_MS) {
    lastScan = now;
    scanMatrix();
  }
  pollSerial();
}

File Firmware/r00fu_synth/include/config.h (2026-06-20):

/*
 * config.h — r00fu_synth hardware configuration (LOCKED PIN MAP)
 * Board: ESP32-S3-DevKitC-1  (the big dual-USB-C dev module)
 *
 * ┌─────────────────────────────────────────────────────────────────────┐
 * │ PSRAM NOTE — READ THIS                                               │
 * │ Mux select S0/S1/S2 reuse GPIO 35/36/37, which on this board are the │
 * │ OCTAL-PSRAM bus. We therefore ship with PSRAM DISABLED so the wiring │
 * │ you already have works unchanged (-DBOARD_HAS_PSRAM=0 in ini).       │
 * │ To enable PSRAM later: move S0->39, S1->47, S2->48 (3 jumpers) and   │
 * │ set the relocated pins below + enable OPI PSRAM in platformio.ini.   │
 * └─────────────────────────────────────────────────────────────────────┘
 */
#pragma once
#include <stdint.h>

// ───────────────────────── Button matrix (8x8) ──────────────────────────
#define MATRIX_ROWS 8
#define MATRIX_COLS 8
#define NUM_BUTTONS (MATRIX_ROWS * MATRIX_COLS)   // 64
// Drive one ROW low at a time, read COLUMNS with pull-ups. Per-key diodes
// give N-key rollover. Flip these two arrays if your diodes are reversed.
static const int ROW_PINS[MATRIX_ROWS] = { 4, 5, 6, 7, 15, 16, 17, 18 };
static const int COL_PINS[MATRIX_COLS] = { 8, 9, 10, 11, 12, 13, 14, 21 };

#define MATRIX_SCAN_INTERVAL_MS 1     // 1 ms scan (spec)
#define MATRIX_DEBOUNCE_COUNT   6     // ~6 ms stable before commit

// ───────────────────── Analog multiplexers (3x 74HC4067) ────────────────
#define MUX_COUNT     3
#define MUX_CHANNELS  16
// Shared 4-bit select bus (S0..S3). GPIO38 is free; 35/36/37 are free only
// because PSRAM is disabled (see banner above).
static const int MUX_SEL_PINS[4] = { 35, 36, 37, 38 };   // S0,S1,S2,S3
#define MUX_A_OUT 1   // ADC1_CH0  -> knobs  0..15
#define MUX_B_OUT 2   // ADC1_CH1  -> knobs 16..31
#define MUX_C_OUT 3   // ADC1_CH2  -> sliders 0..15
#define MUX_SETTLE_US 3                // settle time after channel switch
#define ANALOG_SCAN_INTERVAL_MS 5      // 5 ms (spec)
#define ANALOG_SMOOTHING 0.10f         // filtered = 0.9*prev + 0.1*cur

#define NUM_KNOBS    25                // first 25 of mux A+B (0..31 read)
#define NUM_SLIDERS  15                // first 15 of mux C
#define ADC_RESOLUTION_BITS 12         // 0..4095

// ───────────────────────── I2S DAC (PCM5102A) ───────────────────────────
#define I2S_BCK_PIN   40
#define I2S_LRCK_PIN  41
#define I2S_DOUT_PIN  42
#define SAMPLE_RATE   44100
#define I2S_BITS      16
#define AUDIO_BLOCK_SIZE 64            // frames per audio render block
#define NUM_VOICES    8                // 8-voice polyphony (spec)

// ───────────────────────────── DIN MIDI ─────────────────────────────────
// On UART1 via the GPIO matrix. These are U0TX/U0RX physically and are also
// wired to the on-board USB-UART bridge; use the *native USB* port for data
// so the bridge stays idle. See SETUP.md "Two USB ports".
#define MIDI_TX_PIN   43              // DIN OUT
#define MIDI_RX_PIN   44              // DIN IN  (from 6N138/H11L1 opto)
#define MIDI_BAUD     31250
#define MIDI_UART_NUM 1

// ───────────────────────── Status RGB LED ───────────────────────────────
#define STATUS_LED_PIN 48            // on-board WS2812 on DevKitC-1
#define STATUS_LED_COUNT 1

// ───────────────────────── FreeRTOS task layout ─────────────────────────
#define CORE_IO    0                 // scanners, MIDI, UI, sequencer
#define CORE_AUDIO 1                 // audio only, highest priority
#define PRIO_AUDIO      (configMAX_PRIORITIES - 1)
#define PRIO_BUTTONSCAN 5
#define PRIO_MUXSCAN    4
#define PRIO_MIDI       6
#define PRIO_SEQUENCER  5
#define PRIO_UI         3

// ───────────────────────── Storage / presets ────────────────────────────
#define PRESET_DIR "/presets"
#define SETTINGS_FILE "/settings.json"

// Helper: row,col -> linear button index used everywhere (and by the GUI)
static inline uint8_t btn_index(uint8_t row, uint8_t col) { return row * MATRIX_COLS + col; }

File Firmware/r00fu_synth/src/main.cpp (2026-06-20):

/*
 * main.cpp — boot + system wiring for r00fu_synth.
 *
 * Arduino entry points. setup() runs once on CORE_IO (the Arduino loopTask core)
 * and performs the whole bring-up in dependency order, then hands control to the
 * FreeRTOS tasks created by tasks_start(). loop() is intentionally empty: every
 * recurring job lives in a pinned task (see system/tasks.cpp), so the Arduino
 * loopTask has nothing left to do.
 *
 * INIT ORDER (each step depends on the ones before it):
 *   1. Serial          — native USB-CDC up first so early logs/HELLO reach the GUI.
 *   2. events_init     — the global queue must exist before ANY producer/consumer.
 *   3. presets_init    — mounts LittleFS (format-on-first-boot); storage for 4/5.
 *   4. settings_init   — loads global prefs (needs LittleFS); used by ui_init etc.
 *   5. midi_map_init   — factory map + overlay the GUI's saved assignments.
 *   6. i2s_audio_init  — install the I2S DAC channel (DMA ring; the audio pacer).
 *   7. synth_init      — voices + effects + the core0->core1 command queue.
 *   8. mux/matrix init — analog + button scanners' pin setup.
 *   9. midi/usb/cfg    — DIN + USB-MIDI interfaces and the GUI config link.
 *  10. seq_init        — clear patterns, default tempo, STOPPED.
 *  11. ui_init         — dispatcher state + status LED + startup mode.
 *  12. auto-load       — if g_settings.last_preset is pinned, presets_load() it.
 *  13. tasks_start     — spawn & pin every task; the device is now live.
 *
 * (presets_init() is called exactly once, at step 3; step 12 is the optional
 * last-preset auto-load, not a second mount.)
 *
 * Note on init vs. tasks: the scanners/MIDI/audio modules ALSO call their own
 * init at the top of their task (see tasks.cpp) so pin/DMA ownership lands on the
 * right core. Those inits are idempotent, so calling them here too is harmless
 * and keeps this boot sequence a single readable source of truth.
 */
#include <Arduino.h>

#include "config.h"
#include "events.h"
#include "midi_map.h"

#include "drivers/button_matrix.h"
#include "drivers/mux.h"
#include "drivers/midi_din.h"
#include "drivers/usb_midi.h"
#include "drivers/config_protocol.h"
#include "drivers/pcm5102.h"
#include "audio/synth.h"
#include "sequencer/sequencer.h"
#include "ui/modes.h"
#include "storage/presets.h"
#include "storage/settings.h"
#include "system/tasks.h"

void setup() {
  // 1) Native USB-CDC console (115200 to match the GUI + monitor_speed). A short
  //    settle lets the host enumerate the composite device before we greet it.
  Serial.begin(115200);
  delay(300);

  // 2) Global event bus — everything else may post to it from here on.
  events_init();

  // 3) Filesystem + persisted state. presets_init() mounts LittleFS (formatting
  //    on first boot); settings/midi_map then read their JSON off it.
  const bool fs_ok = presets_init();
  settings_init();
  midi_map_init();
  if (!fs_ok) cfg_log("LittleFS mount failed (presets/settings volatile)");

  // 4) Audio engine. The DAC channel and the synth (voices/effects + the RT-safe
  //    command queue) are created before producers exist; Task_Audio re-affirms
  //    them on CORE_AUDIO (idempotent) so DMA/DSP ownership lands on core 1.
  i2s_audio_init();
  synth_init();

  // 5) Input scanners' pin setup (button matrix + analog muxes).
  mux_init();
  matrix_init();

  // 6) MIDI I/O + the GUI config protocol over USB-CDC.
  midi_din_init();
  usb_midi_init();
  cfg_init();

  // 7) Sequencer (clear patterns, default tempo, STOPPED).
  seq_init();

  // 8) UI dispatcher + status LED + startup mode (reads g_settings).
  ui_init();

  // 9) Auto-load the last preset if the user pinned one (0xFF = none).
  if (g_settings.last_preset != 0xFF && presets_exists(g_settings.last_preset)) {
    if (presets_load(g_settings.last_preset)) cfg_log("auto-loaded last preset");
  }

  // 10) Spawn & pin every task. After this the device is fully live; control
  //     never returns to a meaningful loop().
  tasks_start();

  cfg_log("r00fu_synth boot complete");
}

void loop() {
  // Everything runs in pinned FreeRTOS tasks (system/tasks.cpp). Nothing to do
  // here — yield generously so the Arduino loopTask doesn't hog CORE_IO.
  vTaskDelay(pdMS_TO_TICKS(1000));
}

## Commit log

2026-06-21 Refine case description and assembly instructions
    Removed duplicate description of the case and added a note about the assembly process.
2026-06-21 Enhance readme with tuning instructions
    Updated instructions for tuning switch matrix and knob smoothing.
2026-06-24 Update readme.md with additional case images
    Added images to the case section for better visual representation.
2026-06-24 Replace assembly grooves image with internal case space
    Updated images in the case section of the readme.
2026-06-25 swapped out 3d models for ones with better mounting brackets
